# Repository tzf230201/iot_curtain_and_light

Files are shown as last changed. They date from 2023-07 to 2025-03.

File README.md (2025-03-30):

# IoT Device for Curtain, Main Lighting, and RGB Ambient Light Control  

This project demonstrates an IoT device that controls a curtain motor, main lights, and an ambient light (which can also function as a sleep lamp). The device is powered by an ESP8266 microcontroller and integrates the Universal Telegram Bot library for remote control. The system offers four different modes of operation for flexible and convenient usage.

## Features

- **ESP8266-Based Control**: Enables wireless communication and control using the ESP8266 microcontroller.  
- **Telegram Bot Integration**: Allows real-time remote control via a dedicated Telegram bot.  
- **Four Operation Modes**:  
  1. **Button Control**: Manually control the curtain motor, room lighting, and RGB ambient light using physical buttons.  
  2. **LDR (Light Dependent Resistor) Control**: Automatically adjusts the lighting system based on ambient light levels.  
  3. **Time-Based Control**: Automates curtain and light operations using a Real-Time Clock (RTC) module.  
  4. **Direct Telegram Control**: Provides instant control through commands sent via Telegram.  

## Hardware Specifications  

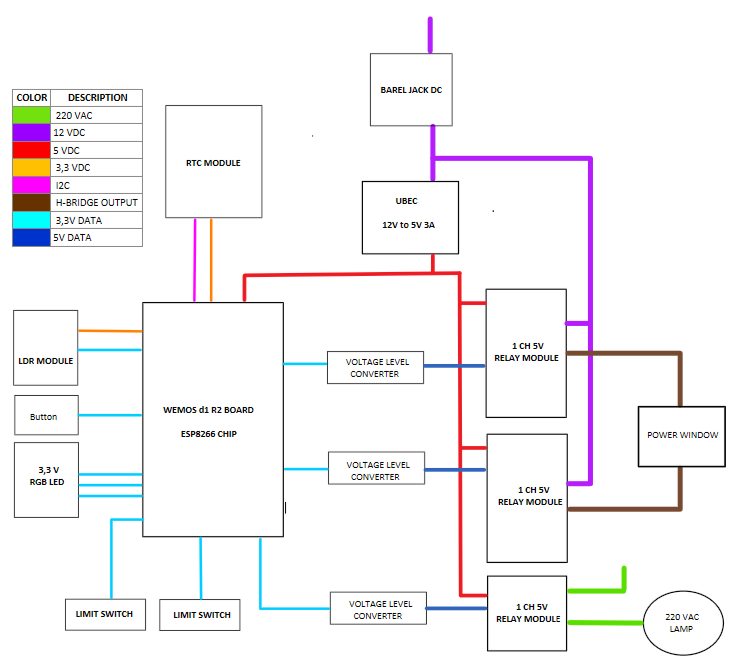
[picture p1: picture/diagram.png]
Diagram
  
*Figure 1: Electronics Diagram*  

## Device Images  

- **Board Design**  
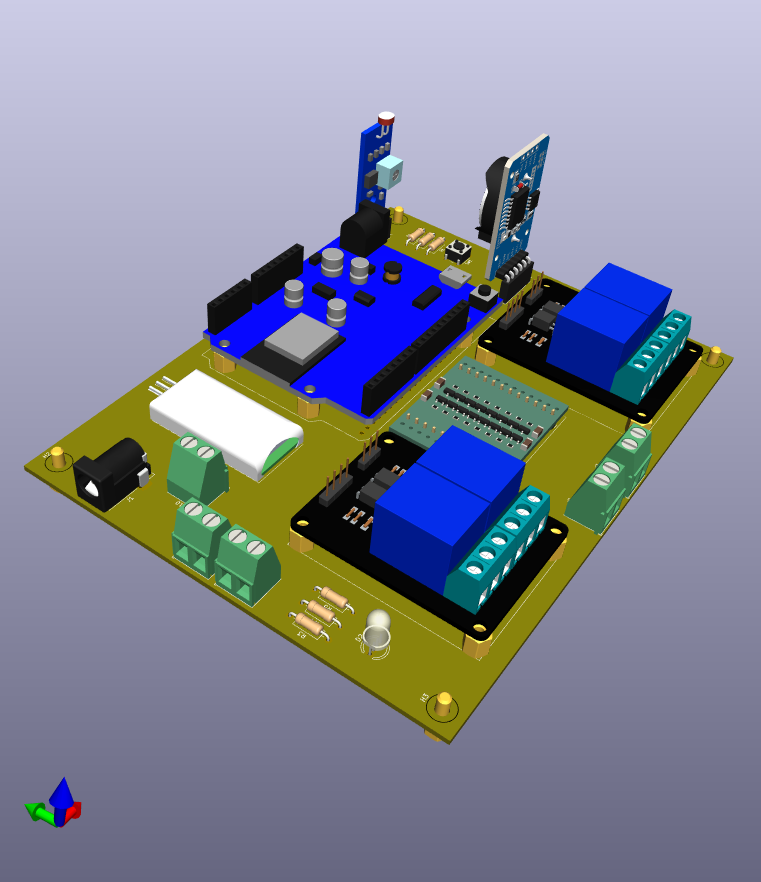
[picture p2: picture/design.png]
Design
  
*Figure 2: 3D Board Design*  

- **Real Hardware**  
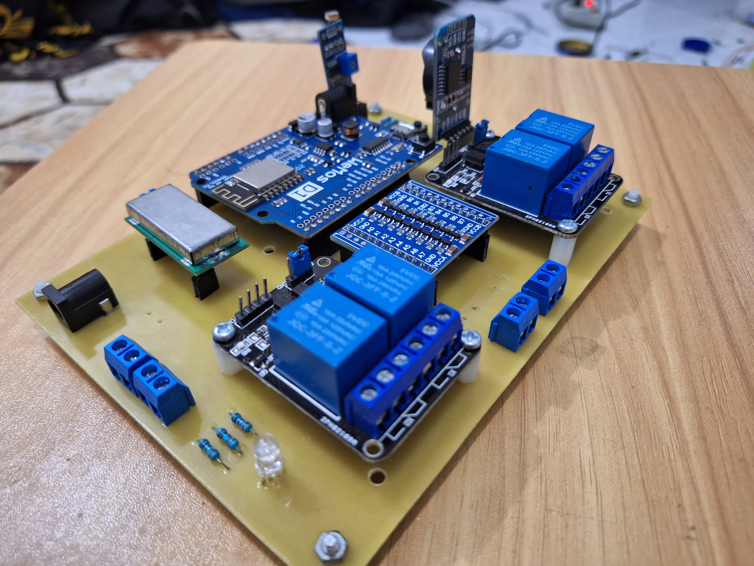
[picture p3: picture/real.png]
Real
  
*Figure 3: Physical Board*  

## Usage  

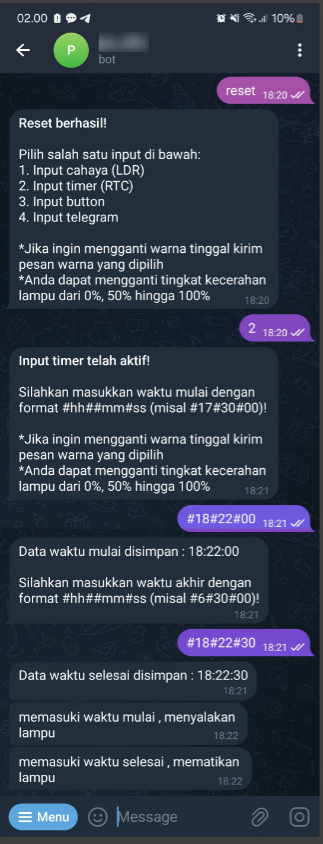
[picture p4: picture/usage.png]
Usage
  
*Figure 4: Device in Action*  

1. **Physical Button Control**: Simply press the physical buttons to manage the curtain motor, room lights, and RGB ambient light.  
2. **Automatic Mode**: The system automatically adjusts the main and ambient lighting based on the surrounding light detected by the LDR sensor.  
3. **Time-Based Mode**: Set schedules for automated curtain and light management.  
4. **Telegram Control**: Send specific commands through Telegram to remotely operate the curtain, room lighting, and ambient light.  

All control methods can be configured through the Telegram bot by sending the `/start` command.

Ask me anything : teukuzikrifatahillah@gmail.com

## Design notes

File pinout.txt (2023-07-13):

Pinout wemos:
 ADC0 (A0) = LDR

GPIO4 (D2) = SDA RTC DS3231
GPIO5 (D1) = SCL RTC DS3231

GPIO14 (D3) = B led
GPIO12 (D4) = R led
GPIO13 (D8) = G led

GPIO0 (D6) = Relay Lampu
GPIO2 (D7) = Relay IN1 motor -> tersa mbung ke 2 trigger relay
GPIO15 (D5) = Relay IN2 motor -> tersambung ke 2 trigger relay

GPIO1 (TX) = Limit switch 1
GPIO3 (RX) = Limit switch 2

D0 = Input button

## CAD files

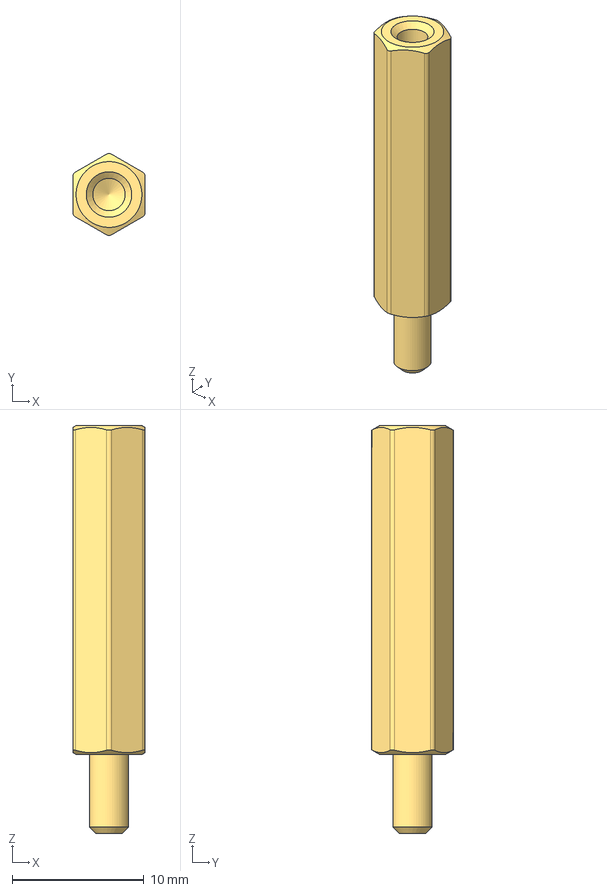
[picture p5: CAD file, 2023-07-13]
IoT_curtain_and_light/necessary library/PCHSN-25.stp
5.50 x 6.23 x 31.0 mm

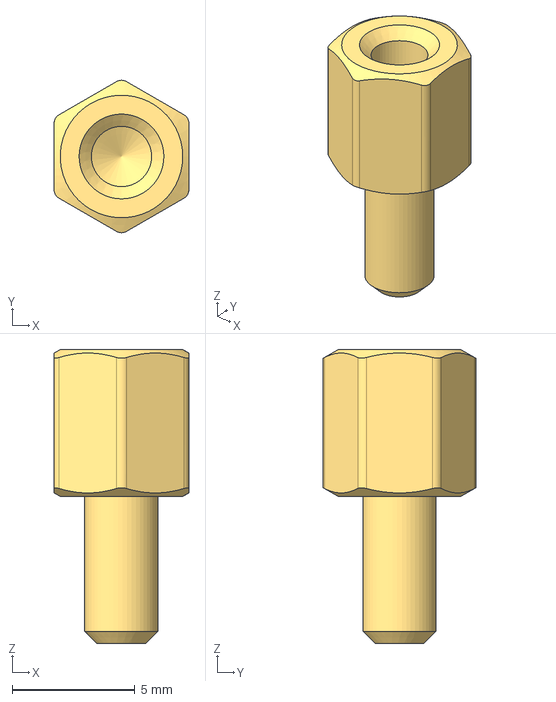
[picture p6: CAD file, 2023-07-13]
IoT_curtain_and_light/necessary library/PCHSN-6.stp
5.50 x 6.23 x 12.0 mm

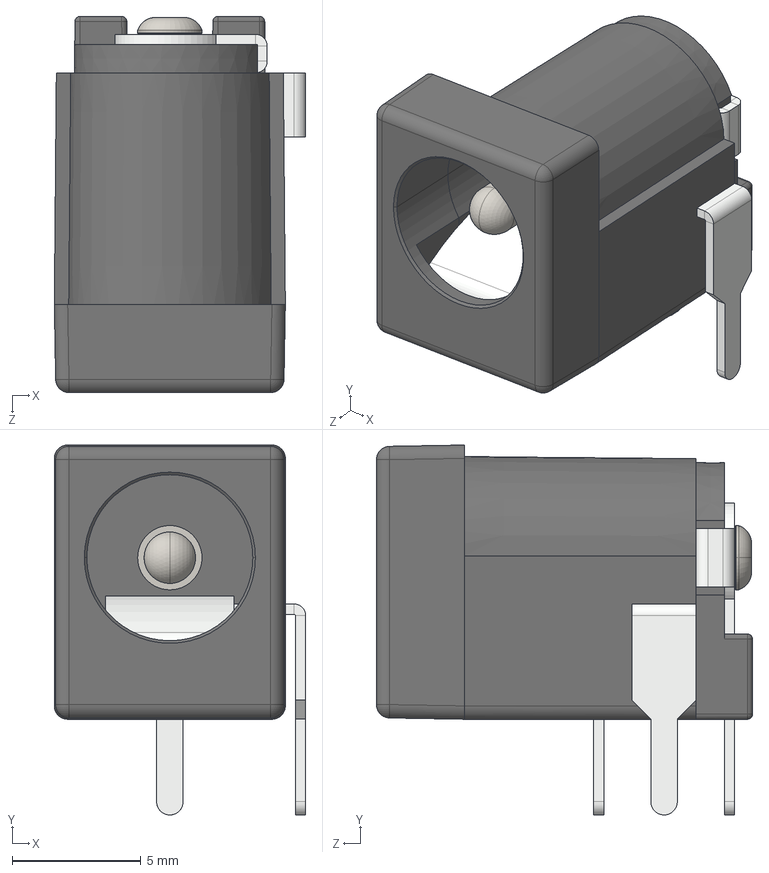
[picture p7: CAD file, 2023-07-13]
IoT_curtain_and_light/necessary library/DC Power Jack 5.5mm x 2.1mm.STEP
9.77 x 14.4 x 14.6 mm

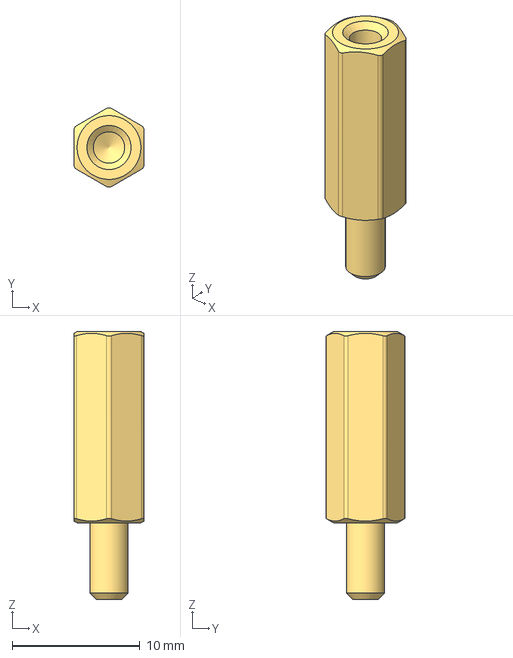
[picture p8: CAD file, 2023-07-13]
IoT_curtain_and_light/necessary library/PCHSN-15.stp
5.50 x 6.23 x 21.0 mm

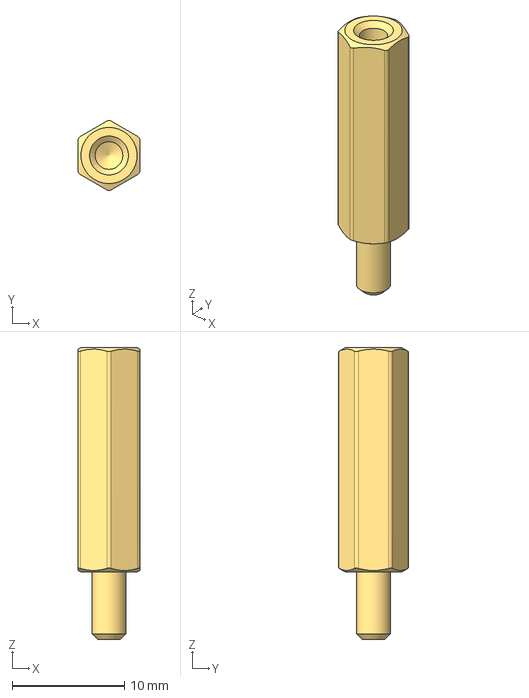
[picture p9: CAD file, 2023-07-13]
IoT_curtain_and_light/necessary library/PCHSN-20.stp
5.50 x 6.23 x 26.0 mm

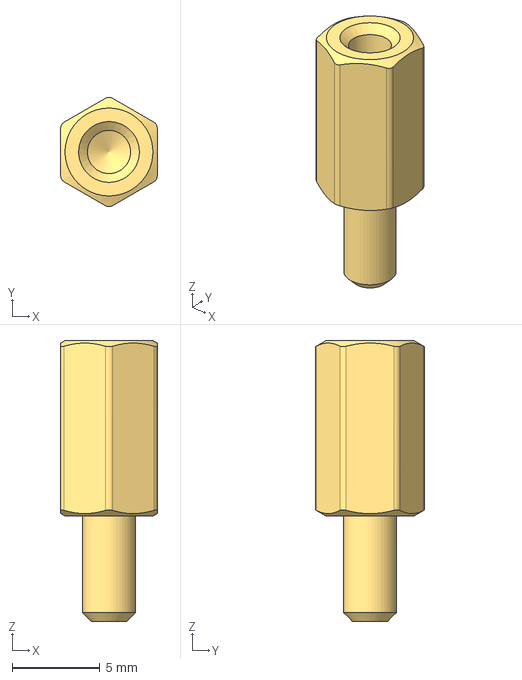
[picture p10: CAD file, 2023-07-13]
IoT_curtain_and_light/necessary library/PCHSN-10.stp
5.50 x 6.23 x 16.0 mm

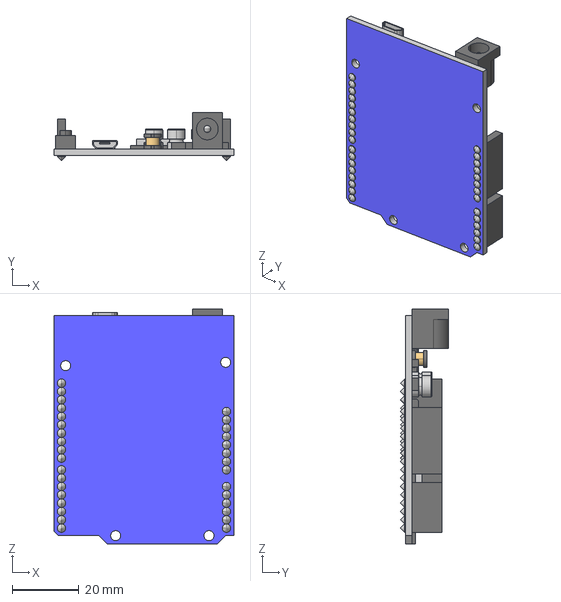
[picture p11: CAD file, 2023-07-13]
IoT_curtain_and_light/necessary library/wemosd1r1.stp
54.0 x 14.5 x 70.5 mm

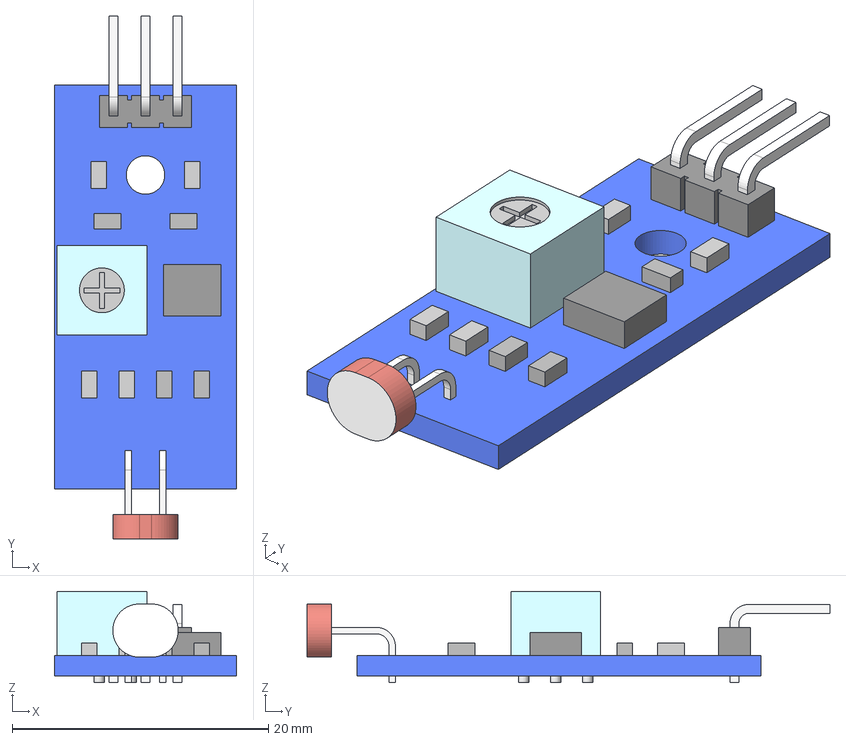
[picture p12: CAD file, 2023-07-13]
IoT_curtain_and_light/necessary library/Light sensor LDR v1.step
14.2 x 40.8 x 7.10 mm

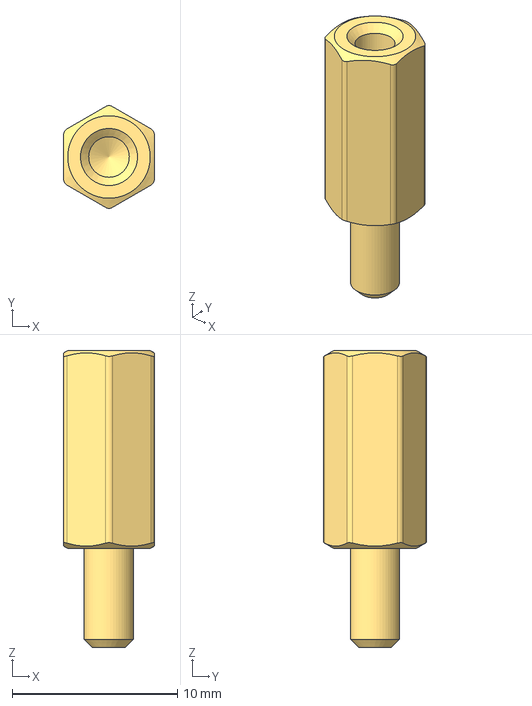
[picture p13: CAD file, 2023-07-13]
IoT_curtain_and_light/necessary library/PCHSN-12.stp
5.50 x 6.23 x 18.0 mm

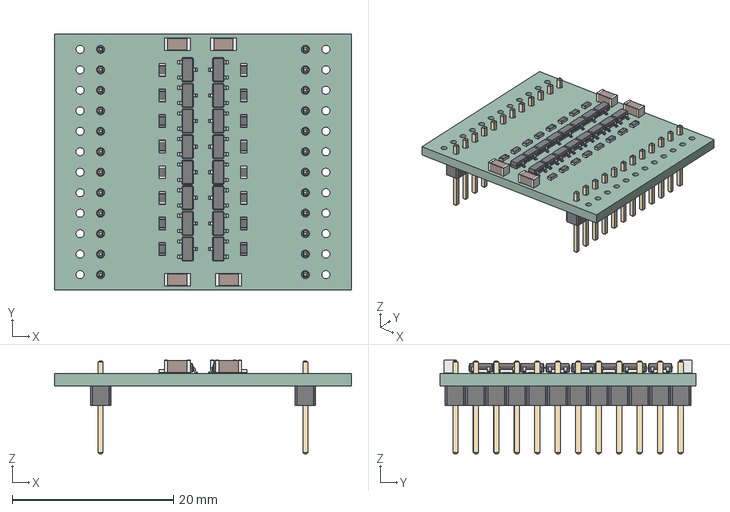
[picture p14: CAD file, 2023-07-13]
IoT_curtain_and_light/necessary library/level_converter.step
36.8 x 31.8 x 11.6 mm
PCB

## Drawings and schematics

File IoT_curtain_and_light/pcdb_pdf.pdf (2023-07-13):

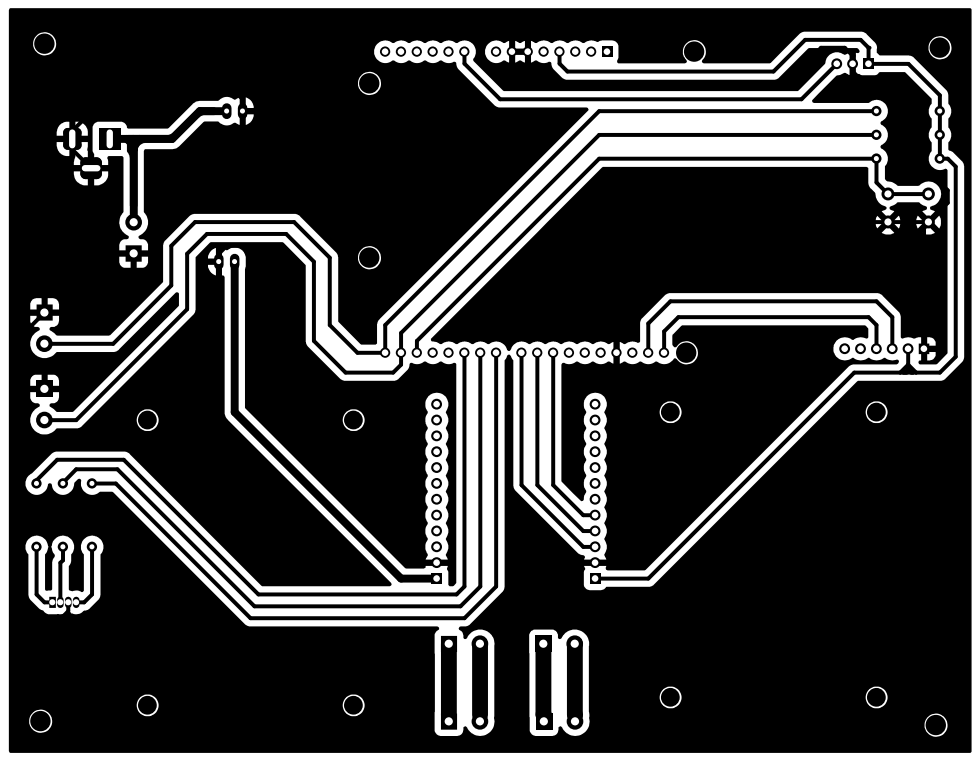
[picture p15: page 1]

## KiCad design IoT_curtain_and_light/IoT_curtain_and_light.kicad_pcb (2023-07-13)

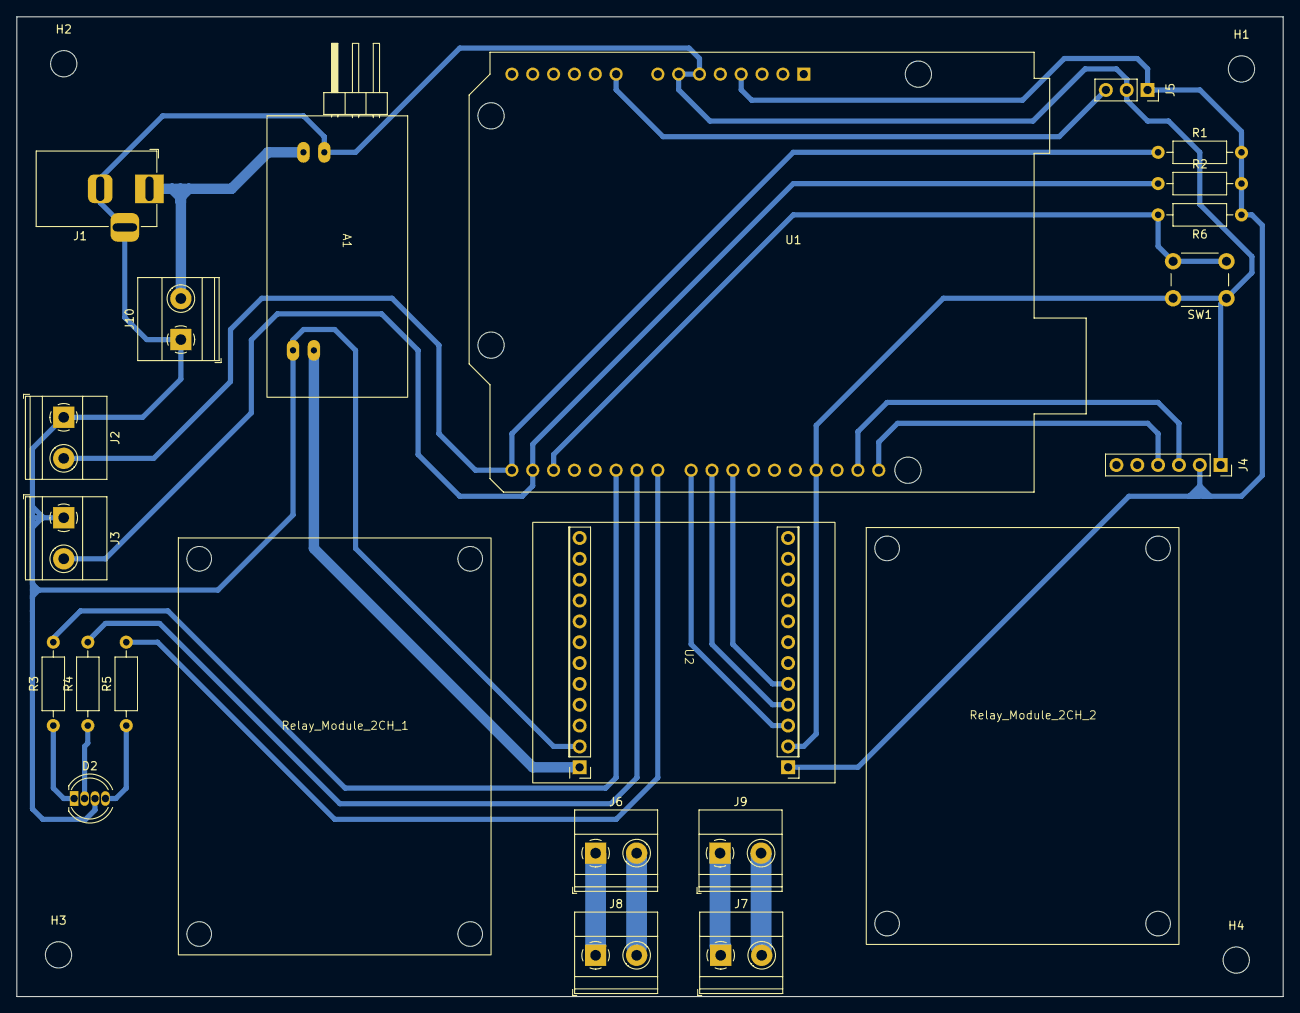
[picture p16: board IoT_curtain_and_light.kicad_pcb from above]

Board: 2 copper layers, 154.3 x 119.4 mm, 27 parts (0 on the bottom side), 23 nets.

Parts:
A1: UBEC_Regulator; UBEC_Reg
D2: LED_RGKB; LED_D5.0mm-4_RGB
H1, H2, H3, H4: MountingHole; MountingHole_3.2mm_M3
J1: Barrel_Jack_Switch; BarrelJack_Horizontal
J2, J3, J6, J7, J8, J9, J10: Screw_Terminal_01x02; TerminalBlock_Phoenix_MKDS-1,5-2_1x02_P5.00mm_Horizontal
J4: Conn_01x06; PinSocket_1x06_P2.54mm_Vertical
J5: Conn_01x03; PinSocket_1x03_P2.54mm_Vertical
R1, R2, R3, R4, R5, R6: R; R_Axial_DIN0207_L6.3mm_D2.5mm_P10.16mm_Horizontal
Relay_Module_2CH_1, Relay_Module_2CH_2: Relay_Module_2CH
SW1: SW_Omron_B3FS; SW_PUSH_6mm
U1: Wemos_D1_R2; wemos_d1_r2
U2: level_converter

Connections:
+3.3V: J4.2, J5.1, R1.2, R2.2, R6.1, U1.4 (3V3), U2.1 (VCCA)
+5V: A1.4 (5v), U2.24 (VCCB)
+12V: A1.2 (VIN), J1.1, J10.2
A0: J5.3, U1.9 (A0)
D0: R6.2, SW1.2, U1.17 (~WAKE/D0)
D3: R3.2, U1.20 (D3)
D4: R4.2, U1.21 (D4)
D5: R5.2, U1.22 (D5)
D6: U1.23 (D6), U2.3 (A0)
D7: U1.24 (D7), U2.4 (A1)
D8: U1.25 (SS/D8), U2.5 (A2)
GND: A1.1 (GND), A1.3 (GND), D2.3 (K), J1.2, J1.3, J2.1, J3.1, J4.1, J5.2, J10.1, SW1.1, U1.6 (GND), U1.7 (GND), U1.29 (GND), U2.2 (GND), U2.23 (GND)
unnamed: D2.4 (BA), R5.1
unnamed: D2.2 (GA), R4.1
unnamed: D2.1 (RA), R3.1
unnamed: J2.2, R1.1, U1.15 (RX)
unnamed: J3.2, R2.1, U1.16 (TX)
unnamed: J6.1, J8.1
unnamed: J6.2, J8.2
unnamed: J7.1, J9.1
unnamed: J7.2, J9.2
SCL: J4.4, U1.32 (SCL/D1)
SDA: J4.3, U1.31 (SDA/D2)

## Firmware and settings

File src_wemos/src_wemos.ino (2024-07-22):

#include <ESP8266WiFi.h>
#include <WiFiClientSecure.h>
#include <UniversalTelegramBot.h>

// Wifi network station credentials
#define WIFI_SSID "pa_afis"//"circle"
#define WIFI_PASSWORD "qwerty123"//"Gr34tw4ll"
// Telegram BOT Token (Get from Botfather)
#define BOT_TOKEN "6080xxxxxx:AAEnxDxxxxxx_ziTF9s0-GOHD19Moxxxxxx"

const unsigned long BOT_MTBS = 500; // mean time between scan messages

X509List cert(TELEGRAM_CERTIFICATE_ROOT);
WiFiClientSecure secured_client;
UniversalTelegramBot bot(BOT_TOKEN, secured_client);
unsigned long bot_lasttime; // last time messages' scan has been done



#include <RTClib.h>
#include <Wire.h>

RTC_DS3231 rtc;

char t[32];

#define RED_PIN D8
#define GREEN_PIN D4
#define BLUE_PIN D3

String color = "red";

void RGBLedInit()
{
  pinMode(RED_PIN, OUTPUT);
  pinMode(GREEN_PIN, OUTPUT);
  pinMode(BLUE_PIN, OUTPUT);
  digitalWrite(BLUE_PIN, 0);
}

void RGBLedWrite(int r, int g, int b)
{
  analogWrite(RED_PIN, map(r,0,100,0,255));
  analogWrite(GREEN_PIN, map(g,0,100,0,255));
  analogWrite(BLUE_PIN, map(b,0,100,0,255));
}

void RGBLedTesting()
{
  RGBLedWrite(100, 100, 100);
  delay(100);
  RGBLedWrite(100, 0, 0);
  delay(100);
  RGBLedWrite(0, 100, 0);
  delay(100);
  RGBLedWrite(0, 0, 100);
  delay(100);
  RGBLedWrite(100, 100, 0);
  delay(100);
  RGBLedWrite(0, 100, 100);
  delay(100);
  RGBLedWrite(100, 0, 100);
  delay(100);
}

int jam_mulai = 17;
int menit_mulai = 30;
int detik_mulai = 00;

int jam_selesai = 6;
int menit_selesai = 30;
int detik_selesai = 00;

void RTCInit()
{
    Wire.begin(SDA, SCL);   //Setting wire (4 untuk SDA dan 5 untuk SCL)
 
    rtc.begin();
    // rtc.adjust(DateTime(F(__DATE__),F(__TIME__)));  //Setting Time
  
  // Kalian dapat menambahkan bagian dibawah ini untuk set manual jam
  // rtc.adjust(DateTime(2014, 1, 21, 3, 0, 0));
}

void RTCTesting()
{
  

  DateTime now = rtc.now();       //Menampilkan RTC pada variable now
 
  Serial.print("Tanggal : ");
  Serial.print(now.day());        //Menampilkan Tanggal
  Serial.print("/");
  Serial.print(now.month());      //Menampilkan Bulan
  Serial.print("/");
  Serial.print(now.year());       //Menampilkan Tahun
  Serial.print(" ");
  
  Serial.print("Jam : ");
  Serial.print(now.hour());       //Menampilkan Jam
  Serial.print(":");
  Serial.print(now.minute());     //Menampilkan Menit
  Serial.print(":");
  Serial.print(now.second());     //Menampilkan Detik
  Serial.println();
}

#define LDR_PIN PIN_A0
int prev_LDR = 0;

#define BTN_PIN D0
int prev_BTN = 0;

const int ledPin = LED_BUILTIN;
int ledStatus = 0;
int prev_ledStatus = 0;

#define NYALA 0
#define MATI 1

#define IN1_PIN D5
#define IN2_PIN D7

#define LAMP_PIN D6

// #define LS1_PIN RX
// #define LS2_PIN TX


unsigned long stopwatch = 0;




void actuatorController(int state)
{
  if(state == 1)
  {
    //motor
    digitalWrite(IN1_PIN, 1);
    digitalWrite(IN2_PIN, 0);
    //lampu
    digitalWrite(LAMP_PIN, NYALA); //active_low
  }
  else
  {
    //motor
    digitalWrite(IN1_PIN, 0);
    digitalWrite(IN2_PIN, 1);
    //lampu
    digitalWrite(LAMP_PIN, MATI);
  }
}

String chat_id;

enum class Mode {
  LDR,//Light Dependent Resistor
  RTC,//Real Time Clock
  BTN,//Button
  MSG//message 

};

Mode mode = Mode::LDR;

// Inisialisasi state mesin
enum class State {
  IDLE,       // State idle
  WELCOME,    // Menerima pesan baru
  CAHAYA,    // Memproses pesan
  TIMER,      // Mengirim balasan pesan
  TIMER2,
  BUTTON,
  TELEGRAM,
  RESET,
  ERROR       // Kesalahan
};

// Inisialisasi variabel state
State state = State::IDLE;

int kecerahan = 100;



void stateMachine(String chat_id,String text)
{

  String parsed0 = getValue(text, '%', 0);
  String parsed1 = getValue(text, '%', 1);


  if (text == "red" || text == "green" || text == "blue")
  {
    color = text;
    String msg = "warna led adalah: ";
    msg += text;
    msg += "\n\n";
    msg += "\\*Jika ingin mengganti warna tinggal kirim pesan warna yang dipilih\n";
    msg += "\\*Anda dapat mengganti tingkat kecerahan lampu dari 0%, 50% hingga 100%\n";
    bot.sendMessage(chat_id, msg, "Markdown");
  }
  else if( (text.indexOf('%') >= 1) && parsed1 == "")
  {
    kecerahan = parsed0.toInt();

    String msg = "kecerahan : ";
    msg += text;
    msg += "\n\n";
    msg += "\\*Jika ingin mengganti warna tinggal kirim pesan warna yang dipilih\n";
    msg += "\\*Anda dapat mengganti tingkat kecerahan lampu dari 0%, 50% hingga 100%\n";
    bot.sendMessage(chat_id, msg, "Markdown");
  }
  else
  {



  switch (state) {
    case State::IDLE: {
      // State idle
      // Tidak melakukan apa-apa
      if (text == "start")
      {
        String msg = "*Selamat Datang!*\n\n";
        msg += "Pilih salah satu input di bawah:\n";
        msg += "1 : Input cahaya (LDR)\n";
        msg += "2 : Input timer (RTC)\n";
        msg += "3 : Input button\n";
        msg += "4 : Input telegram\n\n";
        msg += "\\*Jika ingin mengganti warna tinggal kirim pesan warna yang dipilih\n";
        msg += "\\*Anda dapat mengganti tingkat kecerahan lampu dari 0%, 50% hingga 100%\n";
        bot.sendMessage(chat_id, msg, "Markdown");

        state = State::WELCOME;
      }
      break;
    }
    case State::WELCOME: {
      if (text == "1")
      {
        String msg = "*Input cahaya telah aktif!*\n\n";
        msg += "\\*Jika ingin mengganti warna tinggal kirim pesan warna yang dipilih\n\n";
        msg += "\\*Anda dapat mengganti tingkat kecerahan lampu dari 0%, 50% hingga 100%\n";
        bot.sendMessage(chat_id, msg, "Markdown");

        state = State::CAHAYA;
        mode = Mode::LDR;

      }
      else if (text == "2")
      {
        String msg = "*Input timer telah aktif!*\n\n";
        msg += "Silahkan masukkan waktu mulai dengan format #hh##mm#ss (misal #17#30#00)!\n\n";
        msg += "\\*Jika ingin mengganti warna tinggal kirim pesan warna yang dipilih\n";
        msg += "\\*Anda dapat mengganti tingkat kecerahan lampu dari 0%, 50% hingga 100%\n";
        bot.sendMessage(chat_id, msg, "Markdown");

        state = State::TIMER;
        mode = Mode::RTC;

      }
      else if (text == "3")
      {
        String msg = "*Input button telah aktif!*\n\n";
        msg += "Silahkan gunakan button eksternal yang disediakan!\n\n";
        msg += "\\*Jika ingin mengganti warna tinggal kirim pesan warna yang dipilih\n";
        msg += "\\*Anda dapat mengganti tingkat kecerahan lampu dari 0%, 50% hingga 100%\n";
        bot.sendMessage(chat_id, msg, "Markdown");

        state = State::BUTTON;
        mode = Mode::BTN;

      }
      else if (text == "4")
      {
        String msg = "*Input telegram telah aktif!*\n\n";
        msg += "Silahkan kirim pesan on atau off!\n\n";
        msg += "\\*Jika ingin mengganti warna tinggal kirim pesan warna yang dipilih\n";
        msg += "\\*Anda dapat mengganti tingkat kecerahan lampu dari 0%, 50% hingga 100%\n";
        bot.sendMessage(chat_id, msg, "Markdown");

        state = State::TELEGRAM;
        mode = Mode::MSG;

      }
      else if (text == "reset")
      {
        state = State::RESET;
      }
      else
      {
        bot.sendMessage(chat_id, "perintah keliru\n", "");
      }

      break;
    }
    case State::CAHAYA: {

      

      if (text == "reset")
      {
        state = State::RESET;
      }
      else
      {
        bot.sendMessage(chat_id, "perintah keliru\n", "");
      }


      break;
    }
    case State::TIMER: {

      String sub_text0 = getValue(text, '#', 0);
      String sub_text1 = getValue(text, '#', 1);
      String sub_text2 = getValue(text, '#', 2);
      String sub_text3 = getValue(text, '#', 3);

      Serial.println("rtc");
      Serial.println(sub_text0);
      Serial.println(sub_text1);
      Serial.println(sub_text2);
      Serial.println(sub_text3);


      if (text == "reset")
      {
        state = State::RESET;
      }
      else if(sub_text0 == "")
      {
        String msg = "Data waktu mulai disimpan : ";
        msg += sub_text1 + ":";
        msg += sub_text2 + ":";
        msg += sub_text3 + "\n\n";
        msg += "Silahkan masukkan waktu akhir dengan format #hh##mm#ss (misal #6#30#00)!\n\n";
        bot.sendMessage(chat_id, msg, "Markdown");

        jam_mulai = sub_text1.toInt();
        menit_mulai = sub_text2.toInt();
        detik_mulai = sub_text3.toInt();

        state = State::TIMER2;
      }
      else
      {
        bot.sendMessage(chat_id, "perintah keliru\n", "");
      }

      break;
    }
    case State::TIMER2: {

      String sub_text0 = getValue(text, '#', 0);
      String sub_text1 = getValue(text, '#', 1);
      String sub_text2 = getValue(text, '#', 2);
      String sub_text3 = getValue(text, '#', 3);

      Serial.println("rtc");
      Serial.println(sub_text0);
      Serial.println(sub_text1);
      Serial.println(sub_text2);
      Serial.println(sub_text3);


      if (text == "reset")
      {
        state = State::RESET;
      }
      else if(sub_text0 == "")
      {
        String msg = "Data waktu selesai disimpan : ";
        msg += sub_text1 + ":";
        msg += sub_text2 + ":";
        msg += sub_text3 + "\n\n";
        bot.sendMessage(chat_id, msg, "Markdown");

        jam_selesai = sub_text1.toInt();
        menit_selesai = sub_text2.toInt();
        detik_selesai = sub_text3.toInt();
      }
      else
      {
        bot.sendMessage(chat_id, "perintah keliru\n", "");
      }

      break;
    }
    case State::BUTTON: {

      

      if (text == "reset")
      {
        state = State::RESET;
      }
      else
      {
        bot.sendMessage(chat_id, "perintah keliru\n", "");
      }

      break;
    }
    case State::TELEGRAM: {

      if (text == "reset")
      {
        state = State::RESET;
      }
      else if (text == "on")
      {
        ledStatus = 1;

      }
      else if (text == "off")
      {
        ledStatus = 0;
      }
      else
      {
        bot.sendMessage(chat_id, "perintah keliru\n", "");
      }

      break;
    }
    case State::ERROR: {
      // State kesalahan
      // Menampilkan pesan kesalahan pada serial monitor
      Serial.println("Error");
      bot.sendMessage(chat_id, "ERROR! kirim //start untuk memulai ulang!\n", "");

      state = State::IDLE;
      break;
    }
  }

  }

  if (state == State::RESET)
  {
    String msg = "*Reset berhasil!*\n\n";
    msg += "Pilih salah satu input di bawah:\n";
    msg += "1. Input cahaya (LDR)\n";
    msg += "2. Input timer (RTC)\n";
    msg += "3. Input button\n";
    msg += "4. Input telegram\n\n";
    msg += "\\*Jika ingin mengganti warna tinggal kirim pesan warna yang dipilih\n";
    msg += "\\*Anda dapat mengganti tingkat kecerahan lampu dari 0%, 50% hingga 100%\n";
    bot.sendMessage(chat_id, msg, "Markdown");

    state = State::WELCOME;
  }
}

String getValue(String data, char separator, int index)
{
  int found = 0;
  int strIndex[] = {0, -1};
  int maxIndex = data.length()-1;
 
  for(int i=0; i<=maxIndex && found<=index; i++){
    if(data.charAt(i)==separator || i==maxIndex){
        found++;
        strIndex[0] = strIndex[1]+1;
        strIndex[1] = (i == maxIndex) ? i+1 : i;
    }
  } 
 
  return found>index ? data.substring(strIndex[0], strIndex[1]) : "";
}

void routine()
{
  Serial.println("masuk rutin");
  switch (mode) 
  {
    case Mode::LDR: 
    {
      int read_LDR = analogRead(LDR_PIN) > 512? 0 : 1;
      // Serial.print("ldr = ");
      // Serial.println(read_LDR);
      if(read_LDR != prev_LDR)
      {
        if(read_LDR == 0)
        {
          bot.sendMessage(chat_id, "suasana terdeteksi gelap, menyalakan lampu\n", "");
        }
        else
        {
          bot.sendMessage(chat_id, "suasana terdeteksi terang, mematikan lampu\n", "");
        }
        actuatorController(!read_LDR);

        prev_LDR = read_LDR;
      }
      break;
    }
    case Mode::RTC: 
    {

      DateTime now = rtc.now();       //Menampilkan RTC pada variable now
      Serial.print("Jam : ");
      Serial.print(now.hour());       //Menampilkan Jam
      Serial.print(":");
      Serial.print(now.minute());     //Menampilkan Menit
      Serial.print(":");
      Serial.print(now.second());     //Menampilkan Detik
      Serial.println();

      int mulai = (now.hour() == jam_mulai) && (now.minute() == menit_mulai) && (now.second() >= detik_mulai);
      int selesai = (now.hour() == jam_selesai) && (now.minute() == menit_selesai) && (now.second() >= detik_selesai);

     
      if(selesai)
      {
        ledStatus = 0;
      }

      else if(mulai)
      {
        ledStatus = 1;
      }

      if(ledStatus != prev_ledStatus)
      {
        if(ledStatus == 1)
        {
          actuatorController(1);
          bot.sendMessage(chat_id, "memasuki waktu mulai , menyalakan lampu\n", "");
        }
        else
        {
          actuatorController(0);
          bot.sendMessage(chat_id, "memasuki waktu selesai , mematikan lampu\n", "");
        }
        actuatorController(ledStatus);

        prev_ledStatus = ledStatus;

      }

     
      break;
    }
    case Mode::BTN: 
    {
      int read_BTN = !digitalRead(BTN_PIN);

      if(read_BTN == 1)
      {
        ledStatus = !ledStatus;
        actuatorController(ledStatus);

        if(ledStatus == 1)
        {
          bot.sendMessage(chat_id, "button ditekan, menyalakan lampu\n", "");
        }
        else
        {
          bot.sendMessage(chat_id, "button ditekan, mematikan lampu\n", "");
        }
      }

      break;
    }
    case Mode::MSG: 
    {

      if(ledStatus != prev_ledStatus)
      {
        if(ledStatus == 1)
        {
          bot.sendMessage(chat_id, "lampu menyala\n", "");
        }
        else
        {
          bot.sendMessage(chat_id, "lampu mati\n", "");
        }
        actuatorController(ledStatus);

        prev_ledStatus = ledStatus;

      }
      
      break;
    }
  }
}



void handleNewMessages(int numNewMessages)
{
  Serial.print("handleNewMessages ");
  Serial.println(numNewMessages);

  for (int i = 0; i < numNewMessages; i++)
  {
    chat_id = bot.messages[i].chat_id;
    String text = bot.messages[i].text;

    String from_name = bot.messages[i].from_name;
    if (from_name == "")
      from_name = "Guest";


    stateMachine(chat_id, text);


  }
}




void setup()
{
  //inisialisasi serial
  Serial.begin(115200);
  Serial.println();

  // attempt to connect to Wifi network:
  configTime(0, 0, "pool.ntp.org");      // get UTC time via NTP
  secured_client.setTrustAnchors(&cert); // Add root certificate for api.telegram.org

  //menghubungkan ke jaringan wifi
  Serial.print("Connecting to Wifi SSID ");
  Serial.print(WIFI_SSID);
  WiFi.begin(WIFI_SSID, WIFI_PASSWORD);
  while (WiFi.status() != WL_CONNECTED)
  {
    Serial.print(".");
    delay(500);
  }
  Serial.print("\nWiFi connected. IP address: ");
  Serial.println(WiFi.localIP());

  // Check NTP/Time, usually it is instantaneous and you can delete the code below.
  Serial.print("Retrieving time: ");
  time_t now = time(nullptr);
  while (now < 24 * 3600)
  {
    Serial.print(".");
    delay(100);
    now = time(nullptr);
  }
  Serial.println(now);

  //tanda wifi sudah connect
  pinMode(ledPin, OUTPUT); // initialize digital ledPin as an output.
  for(int i = 0; i < 6; i++)
  {
    digitalWrite(ledPin, LOW); // initialize pin as off (active LOW)
    delay(50);
    digitalWrite(ledPin, HIGH); // initialize pin as off (active LOW)
    delay(50);
  }

  // inisialisasi RTC
  RTCInit();

  //inisialisasi led RGB
  RGBLedInit();
  pinMode(LDR_PIN, INPUT);
  pinMode(BTN_PIN, INPUT);

  pinMode(IN1_PIN, OUTPUT);
  pinMode(IN2_PIN, OUTPUT);
  pinMode(LAMP_PIN, OUTPUT);

  digitalWrite(IN1_PIN, NYALA); //active low
  digitalWrite(IN2_PIN, MATI); //active low
  digitalWrite(LAMP_PIN, MATI); //active low
}

void loop()
{

  //jika waktu internal dikurangi waktu sebelumnya lebih dari 500 ms, maka check pesan masuk
  if (millis() - bot_lasttime > BOT_MTBS) 
  {
    // cek berapa jumlah pesan yang masuk dari telegram
    int numNewMessages = bot.getUpdates(bot.last_message_received + 1);

    // selama jumlah pesan masuk lebih dari 0, maka handle new message bakal dijalankan
    while (numNewMessages)
    {
      Serial.println("got response");
      handleNewMessages(numNewMessages);
      numNewMessages = bot.getUpdates(bot.last_message_received + 1);
    }

    routine();

    bot_lasttime = millis();
  }

  int led_light = map(kecerahan,0,100,0,255);

  if (color == "red")
  {
    analogWrite(RED_PIN, led_light);
    analogWrite(GREEN_PIN, 0);
    analogWrite(BLUE_PIN, 0);
  }
  else if (color == "green")
  {
    analogWrite(RED_PIN, 0);
    analogWrite(GREEN_PIN, led_light);
    analogWrite(BLUE_PIN, 0);
  }
  else if (color == "blue")
  {
    analogWrite(RED_PIN, 0);
    analogWrite(GREEN_PIN, 0);
    analogWrite(BLUE_PIN, led_light);
  }  
}

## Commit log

2024-07-21 update documentation
    [DC Power Jack 5.5mm x 2.1mm.STEP, IoT_curtain_and_light.kicad_pcb, IoT_curtain_and_light.kicad_sch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]
2026-10-26 Reorganize hardware specs and device images in README
    Rearranged hardware specifications and device images sections for better clarity.
